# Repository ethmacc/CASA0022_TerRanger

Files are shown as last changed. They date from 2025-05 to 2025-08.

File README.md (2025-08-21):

# CASA0022 TerRanger

IMG_0298 (1)

## Contents
1. [Introduction](#Introduction)
3. [Materials](#Materials)
4. [Quickstart](#Quickstart)
5. [Advanced Setup](#Advanced-setup)
8. [Future Work](#future-work)
9. [External Links](#External-links)
10. [References](#References)
11. [Contact](#Contact)

## Introduction
### Demo Film
TerRanger Demo Film (https://www.youtube.com/watch?v=eogr--X4ssc)

### What is TerRanger?
This repository contains the code and 3D models required to build the TerRanger Smart Walking Stick, my dissertation project for the MSc Connected Environments course. The TerRanger system consists of 2 key components: the smart walking stick device and a mobile application that pairs with it using Bluetooth Low Energy (BLE). TerRanger uses two STMicroelectronics VL53L5CX tiny LiDAR sensors to map out the terrain below the hiking stick. This data is then translated into point-cloud form and visualized on the mobile application. TerRanger utilises the terrain surface data to estimate erosion along hiking paths, and is essentially a feasibility study to show that trail erosion monitoring can be semi-automated using embedded, low-cost technology.

## Materials
You will need the following materials:
- A 3D printer (with nozzle size no larger than 0.4mm) & filament
- A UV printer (optional)
- An Arduino Nano BLE 33 Sense (rev1 was used in this build, but rev2 can probably also be used with some modifications)
- Protoboard or stripboard
- Electrical wire
- A capacitor (at least 33µF)
- A 10kΩ resistor
- A tactile button
- A 5V stepup converter/regulator (Pololu 5V S7V8F5)
- A LiPo charging module (Adafruit bq24074)
- A 2000mAh LiPo cell
- 2 x VL53L5CX LiDAR Time-of-Flight sensors
- A toggle switch
- 2x 4 pin JST-SH cables
- Assorted M2 screws and bolts
- Washers
- Pin headers and sockets
- Velcro strap
- A walking stick for hiking
- An Android smartphone

## Quickstart
### Hardware
To construct the electronics, the protoboard/stripboard should first be cut to the dimensions 51mm x 62mm. Then, the circuit can be constructed using the following breadboard and schematic as a guide:

circuit_diagram_bb

*Fritzing breadboard diagram*

circuit_diagram_schem

*Fritzing circuit schematic*

The circuit contains a number of subcircuits for the following components:

| **Component subcircuit** | **Remarks** |
|---|---|
| LiDAR sensors | These should be attached using JST-SH cables can for ease of maintenance and disassembly. However, if you wish, they can also be connected with solder joints. Ensure that the four individal lines of the JST-SH connection are connected to the appropriate pins of the Nano 33 MCU (3.3V, ground, I2C - SDA & SCL). The green lines in the breadboard diagram denote the LPn connections, and these MUST be connected to the MCU at the appropriate pins to allow for the individual I2C addresses for each sensor to be assigned correctly. |
| Tactile button | This is connected using a [standard click button circuit](https://docs.arduino.cc/built-in-examples/digital/Button/) to receive a signal when the button is pressed. The 10kΩ resistor is used here. |
| 5V step-up | This part of the circuit boosts the 3.7V of the LiPo battery to 5V so that it can be fed into the Nano 33's VIN pin. The 33µF capacitor is used here to provide some smoothing when the toggle switch is turned on. |
| LiPo charger | This charges the LiPo battery whilst also providing 3.7V from the battery to the 5V step-up. Note that the orientation of the ports should be the same direction as the Nano 33's micro-usb port. This was done for ease of maintenance |

The following real images can also be used as a reference in the protoboard construction:
protoboard

*Protoboard initial build*

protoboard in enclosure

*Protoboard fully connected to components and placed in enclosure*

The device has an approximate endurance of about 8 hours, based on current draw of the circuit as measured below (0.25A).

Circuit current draw as measured with a multimeter

*Circuit current draw as measured with a multimeter*

### Software
The Arduino C++ code for the device is provided in the following folders:
- ```Arduino/DistanceArray_main``` - Push this version to the Nano 33 for the initial device that uses the manual tactile button to trigger the LiDAR sensors to take a sample
- ```Arduino/DistanceArray_ai``` - Push this version to the Nano 33 for the later device that uses gesture recognition (a double tap of the walking stick) to trigger the LiDAR sensors to take a sample

### Enclosure
The enclosure can be printed by exporting the various components from the Fusion360 file in ```Models/3D/```. Ensure the 3D models are printed with sufficiently high quality settings for the best results. The black charging port cover (in the image below) should be printed with flexible polymer, such as TPU. M2 screws and bolts should be used to secure the two halves of the enclosure together.

TPU charging port cover 1
TPU charging port cover 2

*TPU charging port cover*



*Fusion360 model of the device enclosure*

The Fusion360 model can also be used as a reference to attach the electronics inside the enclosure correctly. The 2000mAh LiPo battery should be placed behind the protoboard, and can be pushed into place with a felt ribbon to make removing it easier:




*Removing the battery from the device with a felt ribbon*

If you wish, and have access to a UV printer, you can apply the decals found in ```Models/2D``` to the front face of the enclosure.



*Developing the UV print design*

### Mobile Application
The Mobile Application was designed initially in Figma and then realised with Flutter.

Mobile Application Wireframe

*Wireframe for the TerRanger Mobile Application, designed in Figma*






*Screens from the finished Flutter build*

To download the latest version of the application, navigate to the [Releases tab](https://github.com/ethmacc/CASA0022_TerRanger/releases) and download the latest release.

### Device Operation
Once the device has been assembled and the mobile application installed on your Android smartphone, follow these steps to prepare the device for use:
1. Thread the velcro strap through the slots in the bracket at the back of the enclosure. Use these to securely attach the TerRanger device to your hiking stick
2. Switch on TerRanger by flipping the toggle switch at the top of the enclosure and wait for a few seconds for the startup routine to complete
3. Pair the device by navigating to the ```Devices``` screen in the mobile application and pressing the ```Connect to device``` button.
4. Once done, use the red-orange centre button in the middle of the bottom app bar to create a new hike and start collecting data

## Advanced Setup

This section is intended for advanced makers to provide further details on the TerRanger system and how these can be modified.

### Software

#### Dependencies

The following key libraries were used in the Arduino code:

| **Library** | **Purpose** |
|---|---|
| [vector](https://docs.arduino.cc/libraries/vector/) | Used for [Gyroscopic compensation](#Gyroscopic-compensation) |
| [Wire](https://docs.arduino.cc/language-reference/en/functions/communication/wire/) | Required for I2C communication between the LiDAR sensors and the MCU |
| [SparkFun_VL53L5CX_Library](https://docs.arduino.cc/libraries/sparkfun-vl53l5cx-arduino-library/) | Required to interface with the firmware for the VL53L5CX |
| [ArduinoBLE](https://docs.arduino.cc/libraries/arduinoble/) | Used to set a device name and create a BLE characteristic that the data from the sensors can be written to |
| [Arduino_LSM9DS1](https://docs.arduino.cc/libraries/arduino_lsm9ds1/) | To interface with the LSM9DS1 IMU, used for [Gyroscopic compensation](#Gyroscopic-compensation) |

#### Sensor tuning

Image of two VL53L5CX sensors attached to the circuit

*Two VL53L5CX sensors attached to the circuit*

The VL53L5CX sensors can be tuned to change their sampling frequency, distance array size and ranging mode, which will have effects on device performance. This can be done by calling the appropriate functions from the imported Sparkfun library in the main Arduino code, for example:

| **Function** | **Use** |
|---|---|
| `SparkFun_VL53L5CX.setResolution()` | To change distance array size between 4x4 and 8x8 |
| `SparkFun_VL53L5CX.setRangingMode()` | To set ranging mode. It is possible to select either continuous or autonomous. Continuous uses more power but is more frequent |
| `SparkFun_VL53L5CX..setRangingFrequency()` | To set ranging frequency in continous mode. This has been set to the maximum of 60Hz in the code, to minimize lag time |

For more information, see the Sparkfun VL53L5CX library GitHub repo and VL53L5CX datasheet and manual under [External Links](#External-links))

#### Gyroscopic compensation

The walking stick could be oriented in a direction that is not orthogonal to the ground plane when a sample is taken. Therefore the vector library was used, and the functions ```calculatePitch``` and ```calculateYaw``` make use of this and the [acceleration to pitch & yaw forumla](https://wiki.dfrobot.com/How_to_Use_a_Three-Axis_Accelerometer_for_Tilt_Sensing) to convert the accelerometer readings to pitch and yaw angles in degrees. These angles are transmitted to the mobile application via Bluetooth.

#### Bluetooth

The device connects to the mobile application via Bluetooth Low Energy, using the Arduino BLE library. The buffer size (for transmitting data) has been set up dynamically using variables to ensure it will change should you choose to set the VL53L5CX to the 8x8 resolution (it is set to 4x4 by default and in the code). Note that this may also require changes to the peripheral BLE device code in the mobile application as it is currently configured to receive the appropriate number of btyes for the 4x4 resolution, not the 8x8.

### Edge AI model

If you elect to use the gesture recognition version of the Arduino code in ```Arduino/DistanceArray_ai/```, you will find that it uses a TinyML or Edge AI model to power the gesture recognition functionality. The model embedded in the code as a library is a Convolutional Neural Network (CNN), that has been trained on accelerometer data from performing the gesture of double tapping the hiking stick on the ground.



*Model architecture of the CNN used for gesture recognition in the DistanceArray_ai.ino file*

Other architectures tested included a Recurrent Neural Network (using Long Short Term Memory layers) and a hybrid model with both LSTM and Convolutional layers. The CNN model outperformed the other two architectures by far.



*Comparison of performance across different model architectures*

Using Edge Impulse, it is possible to clone the project and train it on your own data or make further adjustments to the model. To visit the Edge Impulse project page, see [External Links](#External-links))

### Mobile Application

#### Dependencies

The key libraries that have been used in the code are:

| **Library** | **Purpose** |
|---|---|
| [flutter_reactive_ble](https://pub.dev/packages/flutter_reactive_ble) | For establishing the Bluetooth Low Energy connection to the device |
| [permission_handler](https://pub.dev/packages/permission_handler) | For handling location and Bluetooth permissions |
| [provider](https://pub.dev/packages/provider) | To provide [app state management](https://docs.flutter.dev/get-started/fundamentals/state-management) |
| [sqflite](https://pub.dev/packages/sqflite) | To persist data in the background in the form of a SQL database |
| [flutter_map](https://pub.dev/packages/flutter_map) & [flutter_map_location_marker](https://pub.dev/packages/flutter_map_location_marker) | To display a map widget |
| [latlong2](https://pub.dev/packages/latlong2) & [geolocator](https://pub.dev/packages/geolocator) | To get the position of the user when a sample is taken |
| [fl_chart](https://pub.dev/packages/fl_chart), [vector_math](https://pub.dev/packages/vector_math) & [ditredi](https://pub.dev/packages/ditredi) | To manipulate and visualize the data from the sensors |
| [share_plus](https://pub.dev/packages/share_plus) | To provide backup functionality for the local SQL database where the data is stored |

#### Developer setup

If you wish to develop the mobile application further, first clone this entire repository with:

```powershell
git clone https://github.com/ethmacc/CASA0022_TerRanger/
```

After which, run the following command to fix and issues in the code and install dependencies (using the ```pubspec.yaml``` file in application root folder):

```powershell
flutter clean

flutter pub get
```

To run the application in a connected Android Device or Emulator, use:

```powershell
flutter run
```

The application can be built into and apk and installed using the following commands:

```powershell
flutter build apk
flutter install
```

Note that if you want to push an upgrade to an existing version of the application on your Android device without overwriting the existing data collected, you should use:

```powershell
adb install -r "smarthiking_app\build\app\outputs\apk\release\app-release.apk"
```

instead of ```flutter install```

If you wish to load data from the 3 hikes that were conducted during the course of this project, find them in the folder ```Data/database_backups/``` and load them into your app by using the load backup function on the backups screen.

#### Algorithms
The distance array (from the VL53L5CX sensors) to point-cloud algorithm is based on scaling a list of vectors that point to each of the grid points in the sensor's field of view. This was tested and visualised initially in the Python notebooks  ```/Data/byte_decoder.ipynb``` and ```/Data/byte_decoder_4x4.ipynb```, which can also be used for further development.

newplot (1)

*The vector list visualised as a vector field using plotly in the Python notebook*

The vector list has been copied and hardcoded into ```smarthiking_app/lib/screens/sample_detail.dart``` and is used in the function
```dart
List<List> parseAndScalePts(String rawData) {...}
```
to generate the point cloud from the distance array received from the sensors.

The erosion estimation algorthim is based on the Cross-Section Analysis (CSA) method and formula as described in [Olive and Marion (2009)](#references):



*Diagram illustraing the CSA method, taken from [Olive and Marion (2009)](#references)*

This is implemented in ```smarthiking_app/lib/screens/sample_detail.dart``` in the function:
```dart
double calcErosion (List<List> sectionLists) {...}
```

## Future Work
A PCB design was developed towards the end of the project, but this was not manufactured or tested. It can be found in ```Models/2D```. A future version of the project might involve miniaturising the device further, taking and advantage of the reduced size of the electronics with a dedicated PCB and surface mount-components.




*PCB design schematic (left) and 3D model (right)*

It may also be possible to upgrade the sensors, which during testing were found to be less accurate than desired. The VL53L8CX, an improved model that is more able to cope with environmental factors such as high ambient light, is just starting to become more widely available.

Lastly, it would be an interesting exercise to try adapting the device to another use case, such as surveying for potholes. Pothole damage repair costs the UK approximately £143.5 million annually [(Asphalt Industry Alliance, 2024)](#references).

## External Links

### Sparkfun VL53L5CX library
https://github.com/sparkfun/SparkFun_VL53L5CX_Arduino_Library

### VL53L5CX manual & datasheet
https://www.st.com/resource/en/user_manual/um2884-a-guide-to-using-the-vl53l5cx-multizone-timeofflight-ranging-sensor-with-a-wide-field-of-view-ultra-lite-driver-uld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

https://www.st.com/resource/en/datasheet/vl53l5cx.pdf

### Edge Impulse Project
https://studio.edgeimpulse.com/public/732758/live

## References

### In text

Asphalt Industry Alliance. (2024). *Annual Local Authority Road Maintenance Survey Report*. 2024.

Olive, N. D. and Marion, J. L. (2009). *‘The influence of use-related, environmental, and managerial factors on soil loss from recreational trails’. Journal of Environmental Management*, 90 (3), pp. 1483–1493. doi: 10.1016/j.jenvman.2008.10.004.

### Code snippets & tutorials

Makadiya, K (2024). *Flutter Pull to Refresh: How to Implement, Customize, and Handle Errors. Dhiwise.com*. Available at: https://www.dhiwise.com/post/flutter-pull-to-refresh-how-to-implement-customize (Accessed 20 Aug. 2025).

Lee, S. (2024). *Safely Backing Up Sqlflite in Flutter. Medium*. Available at: https://medium.com/@soojlee0701/safely-backing-up-sqlflite-in-flutter-120718588dd5 (Accessed 20 Aug. 2025).

Nitesh (2021). *Flutter polyline distance with google_maps_flutter plugin. Stack Overflow*. Available at: https://stackoverflow.com/questions/66181115/flutter-polyline-distance-with-google-maps-flutter-plugin (Accessed 21 Aug. 2025).

VitLit (2019). *Center poly line google maps plugin flutter fit to screen google map. Stack Overflow*. Available at: https://stackoverflow.com/questions/57986855/center-poly-line-google-maps-plugin-flutter-fit-to-screen-google-map (Accessed 21 Aug. 2025).

## Contact
If you have any suggestions or would like to contribute to this project, please submit a pull request and/or contact me using my social links on my profile

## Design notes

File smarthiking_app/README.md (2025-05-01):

# smarthiking_app

A new Flutter project.

## Getting Started

This project is a starting point for a Flutter application.

A few resources to get you started if this is your first Flutter project:

- [Lab: Write your first Flutter app](https://docs.flutter.dev/get-started/codelab)
- [Cookbook: Useful Flutter samples](https://docs.flutter.dev/cookbook)

For help getting started with Flutter development, view the
[online documentation](https://docs.flutter.dev/), which offers tutorials,
samples, guidance on mobile development, and a full API reference.

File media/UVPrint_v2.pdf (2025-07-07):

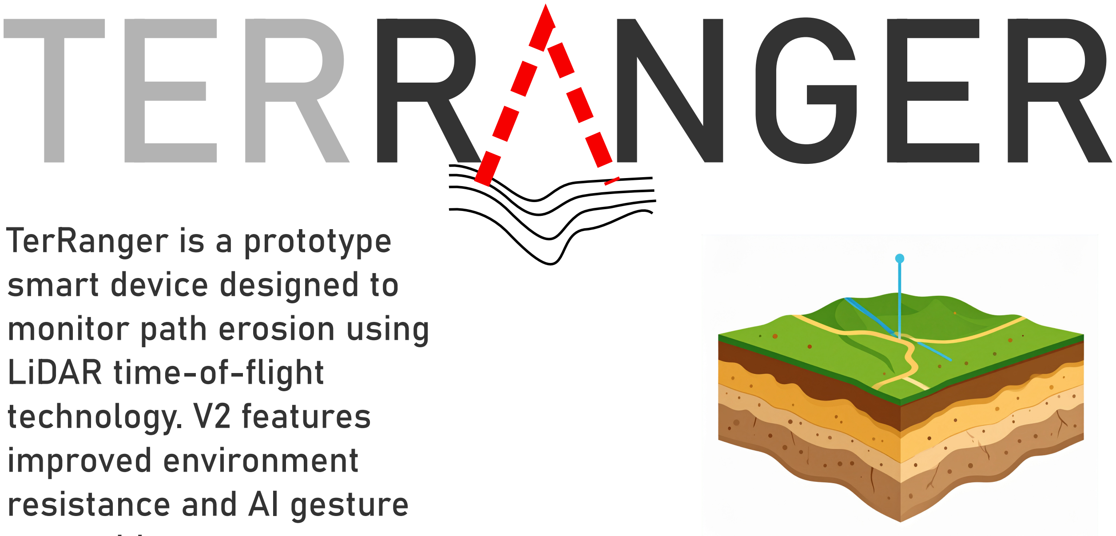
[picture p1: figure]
TERR NGER; TerRanger is a prototype smart device designed to monitor path erosion using LiDAR time-of-flight technology. V2 features improved environment resistance and AI gesture
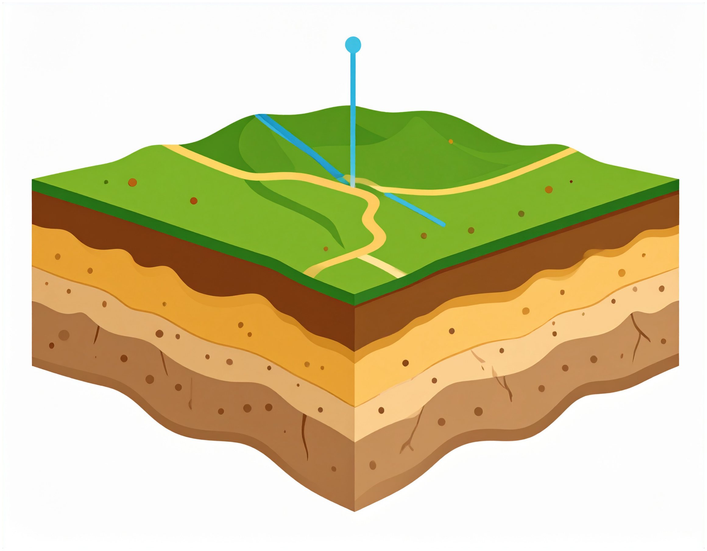
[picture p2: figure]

recognition.

TerRanger v2.0.2025

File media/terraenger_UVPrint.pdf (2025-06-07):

# TERRAENGER

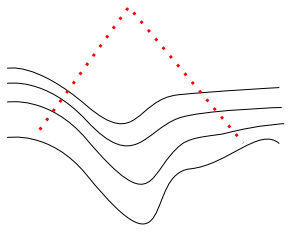
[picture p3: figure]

Terraenger is a prototype
smart device designed to
monitor path erosion using LiDAR time-of-flight
technology

Terraenger v1.0.2025

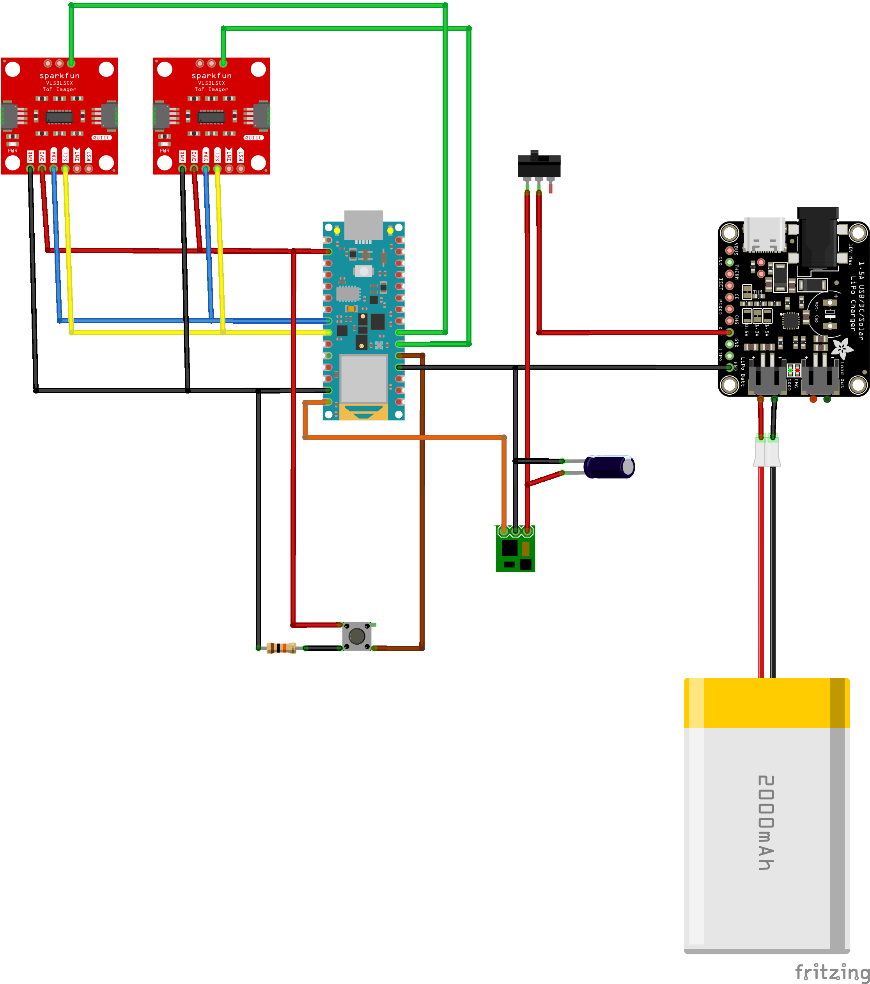
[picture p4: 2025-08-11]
Models/2D/circuit_diagram_bb.png

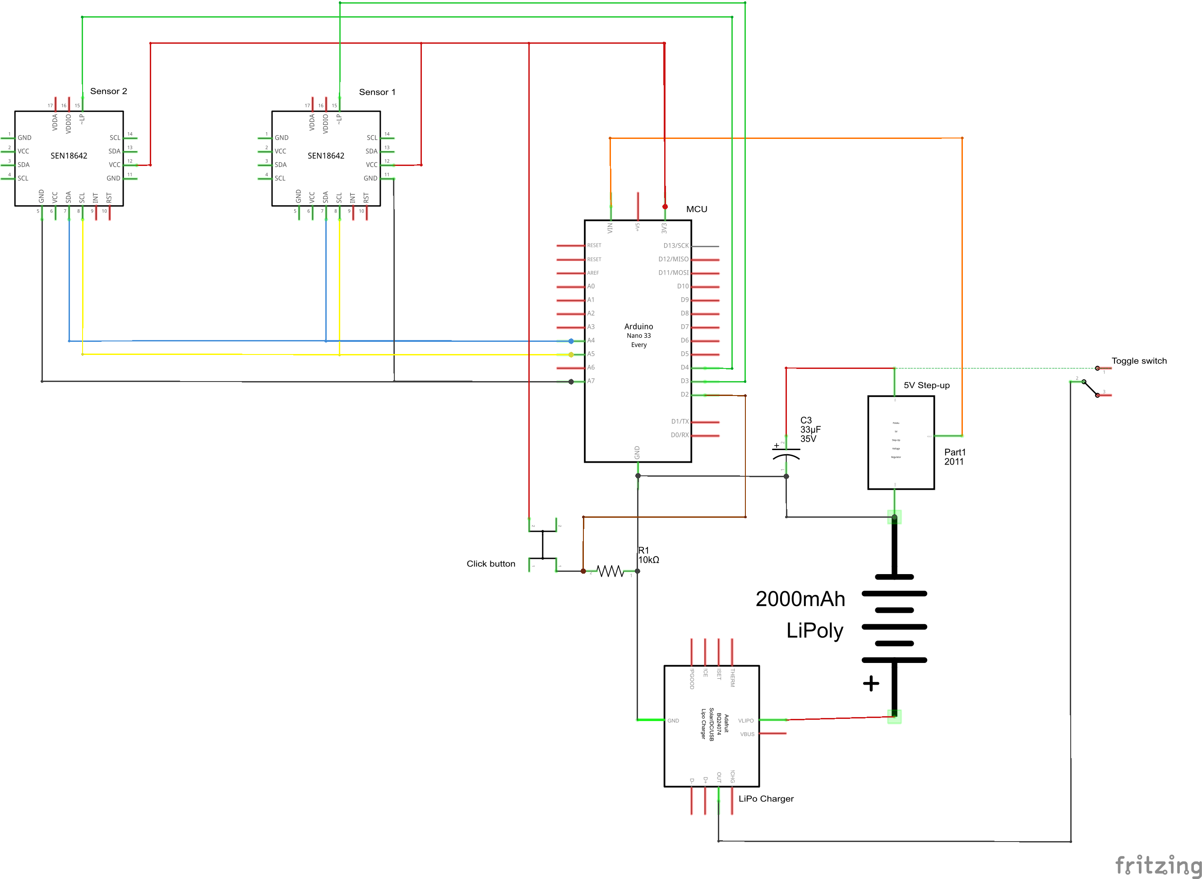
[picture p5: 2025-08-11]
Models/2D/circuit_diagram_schem.png

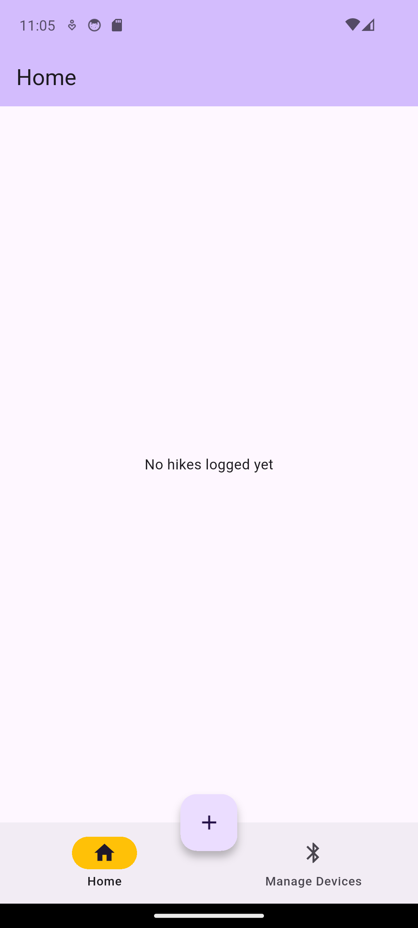
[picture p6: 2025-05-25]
smarthiking_app/flutter_01.png

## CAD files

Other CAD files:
Models/3D/TerRanger_main.f3d

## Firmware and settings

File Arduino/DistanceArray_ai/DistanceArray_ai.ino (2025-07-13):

#include <vector>
#include <Wire.h> //include Wire for I2C
#include <SparkFun_VL53L5CX_Library.h> //http://librarymanager/All#SparkFun_VL53L5CX
#include <ArduinoBLE.h>
#include <Arduino_LSM9DS1.h>
#include <TerRanger_inferencing.h>

SparkFun_VL53L5CX tof_1;
SparkFun_VL53L5CX tof_2;
VL53L5CX_ResultsData measurementData_1; // Result data class structure, 1356 byes of RAM
VL53L5CX_ResultsData measurementData_2;

uint8_t percent = 30; // Set sharpening percentage
uint8_t freq = 30; // Set ranging frequency
uint8_t res = 4*4; // Set sensor resolution

int imageResolution = 0; //Used to pretty print output
int imageWidth = 0; //Used to pretty print output

#define LPn_1 D3
#define LPn_2 D4

#define buttonPin D2 //Set pin for the button
int buttonState = 0;

// Bluetooth® Low Energy Service
#define BUFFER_SIZE ( (res * 2 ) + 2) * 2 // Buffer size is resolution x 2 sensors x 2 bytes plus 2 * 2 bytes for acc data
BLEService tofService = BLEService("185B");
BLECharacteristic tofChar = BLECharacteristic("2C0A", BLERead | BLENotify, BUFFER_SIZE, false); 

#define CONVERT_G_TO_MS2    9.80665f
#define MAX_ACCEPTED_RANGE  2.0f

static bool debug_nn = false; // Set this to true to see e.g. features generated from the raw signal
static uint32_t run_inference_every_ms = 30;
static rtos::Thread inference_thread(osPriorityLow);

static float buffer[EI_CLASSIFIER_DSP_INPUT_FRAME_SIZE] = { 0 };
static float inference_buffer[EI_CLASSIFIER_DSP_INPUT_FRAME_SIZE];

const char *prediction = "false";

/* Forward declaration */
void run_inference_background();

float accX, accY, accZ;

unsigned long pressTime = millis();

void setup()
{
  Serial.begin(115200);
  delay(1000);  

  // Set LED for BLE connection indicator
  pinMode(LED_BUILTIN, OUTPUT);

  //Initialise I2C
  Wire.begin(); //This resets to 100kHz I2C
  Wire.setClock(400000); //Sensor has max I2C freq of 400kHz 
  
  //Initialise ToF
  Serial.println("Initializing ToF sensors. This can take up to 10s. Please wait.");

  //Initialise ToF cams
  initialiseToF(1);
  initialiseToF(2);

  imageResolution = tof_1.getResolution(); //Query sensor for current resolution - either 4x4 or 8x8
  imageWidth = sqrt(imageResolution); //Calculate printing width

  //IMU initialisation
  if (!IMU.begin()) {
    Serial.println("Failed to initialize IMU!");
    while (1);
  }
  Serial.println("IMU initialised");

  // BLE begin initialization
  if (!BLE.begin()) {
    Serial.println("starting BLE failed!");
    while (1);
  }
  Serial.println("BLE initialised");

  //BLE set device name, UUIDs 
  BLE.setLocalName("SH_v1");
  BLE.setDeviceName("SH_v1");

  BLE.setAdvertisedService(tofService);
  tofService.addCharacteristic(tofChar);
  BLE.addService(tofService);
  BLE.advertise();

  //Edge Impulse model axes check
  if (EI_CLASSIFIER_RAW_SAMPLES_PER_FRAME != 6) {
        ei_printf("ERR: EI_CLASSIFIER_RAW_SAMPLES_PER_FRAME should be equal to 6 (the 6 sensor axes)\n");
        return;
  }

  inference_thread.start(mbed::callback(&run_inference_background));
  Serial.println("Inference thread started");

  Serial.println("All initialisation complete");
}

void loop()
{
  // wait for a Bluetooth® Low Energy central
  BLEDevice central = BLE.central();

  // if a central is connected to the peripheral:
  if (central) {
    Serial.print("Connected to central: ");
    // print the central's BT address:
    Serial.println(central.address());
    // turn on the LED to indicate the connection:
    digitalWrite(LED_BUILTIN, HIGH);

    while (central.connected()) {
      ///Poll sensors and load buffer//
      // Determine the next tick (and then sleep later)
      uint64_t next_tick = micros() + (EI_CLASSIFIER_INTERVAL_MS * 1000);

      // roll the buffer -3 points so we can overwrite the last one
      numpy::roll(buffer, EI_CLASSIFIER_DSP_INPUT_FRAME_SIZE, -6);

      // read to the end of the buffer
      IMU.readAcceleration(
          buffer[EI_CLASSIFIER_DSP_INPUT_FRAME_SIZE - 6],
          buffer[EI_CLASSIFIER_DSP_INPUT_FRAME_SIZE - 5],
          buffer[EI_CLASSIFIER_DSP_INPUT_FRAME_SIZE - 4]
      );

      IMU.readGyroscope(
          buffer[EI_CLASSIFIER_DSP_INPUT_FRAME_SIZE - 3],
          buffer[EI_CLASSIFIER_DSP_INPUT_FRAME_SIZE - 2],
          buffer[EI_CLASSIFIER_DSP_INPUT_FRAME_SIZE - 1]
      );

      for (int i = 0; i < 6; i++) {
          if (fabs(buffer[EI_CLASSIFIER_DSP_INPUT_FRAME_SIZE - 6 + i]) > MAX_ACCEPTED_RANGE) {
              buffer[EI_CLASSIFIER_DSP_INPUT_FRAME_SIZE - 6 + i] = ei_get_sign(buffer[EI_CLASSIFIER_DSP_INPUT_FRAME_SIZE - 6 + i]) * MAX_ACCEPTED_RANGE;
          }
      }

      buffer[EI_CLASSIFIER_DSP_INPUT_FRAME_SIZE - 6] *= CONVERT_G_TO_MS2;
      buffer[EI_CLASSIFIER_DSP_INPUT_FRAME_SIZE - 5] *= CONVERT_G_TO_MS2;
      buffer[EI_CLASSIFIER_DSP_INPUT_FRAME_SIZE - 4] *= CONVERT_G_TO_MS2;

      // check if the pushbutton is pressed. If it is, the buttonState is HIGH:
      
      if (prediction == "true" && millis() - pressTime > 1000) {
        Serial.println("prediction true");
        
        Serial.println("ToF cam1");
        updateDistance(1);
        Serial.println("ToF cam2");
        updateDistance(2);

        if (IMU.accelerationAvailable()) {
          IMU.readAcceleration(accX, accY, accZ);
        }

        float consX = constrain(accX, -1.0, 1.0);
        float consY = constrain(accY, -1.0, 1.0);
        float consZ = constrain(accZ, -1.0, 1.0);

        int roll = calculateRoll(consX, consY, consZ);
        int pitch  = calculatePitch(consX, consY, consZ);

        Serial.println(roll);
        Serial.println(pitch);

        uint16_t roll16 = uint16_t(roll + 180);
        uint16_t pitch16 = uint16_t(pitch + 180);

        Serial.println(roll16);
        Serial.println(pitch16);
          
        uint16_t acc_data[2] = {roll16, pitch16};

        uint16_t * combined_tof = new uint16_t[res * 2];
        std::copy(measurementData_1.distance_mm, measurementData_1.distance_mm + res, combined_tof);
        std::copy(measurementData_2.distance_mm, measurementData_2.distance_mm + res, combined_tof + res);

        uint16_t * all_data = new uint16_t[(res * 2) + 2];
        std::copy(combined_tof, combined_tof + (res * 2), all_data);
        std::copy(acc_data, acc_data + 2, all_data + (res * 2));
        
        tofChar.writeValue(all_data, BUFFER_SIZE);
        pressTime = millis();
      }

      // and wait for next tick
      uint64_t time_to_wait;
      if (micros() >= next_tick) {
          time_to_wait = 0;
      } else {
          time_to_wait = next_tick - micros();
      }
      
      delay((int)floor((float)time_to_wait / 1000.0f));
      delayMicroseconds(time_to_wait % 1000);
    }
     // when the central disconnects, turn off the LED:
    digitalWrite(LED_BUILTIN, LOW);
    Serial.print("Disconnected from central: ");
    Serial.println(central.address());
  }
}
 
void updateDistance(int cam) {
  switch (cam) {
    case 1:
      //Poll sensor for new data
      if (tof_1.isDataReady() == true)
      {
        if (tof_1.getRangingData(&measurementData_1)) //Read distance data into array
        {
          //tofChar.writeValue(measurementData_1.distance_mm, 128);
          //The ST library returns the data transposed from zone mapping shown in datasheet
          //Pretty-print data with increasing y, decreasing x to reflect reality
          for (int y = 0 ; y <= imageWidth * (imageWidth - 1) ; y += imageWidth)
          {
            for (int x = imageWidth - 1 ; x >= 0 ; x--)
            {
              Serial.print("\t");
              Serial.print(measurementData_1.distance_mm[x + y]);
            }
            Serial.println();
          }
          Serial.println();
        }
      }
      break;
    case 2:
      //Poll sensor for new data
      if (tof_2.isDataReady() == true)
      {
        if (tof_2.getRangingData(&measurementData_2)) //Read distance data into array
        {
          //tofChar.writeValue(measurementData_1.distance_mm, 128);
          //The ST library returns the data transposed from zone mapping shown in datasheet
          //Pretty-print data with increasing y, decreasing x to reflect reality
          for (int y = 0 ; y <= imageWidth * (imageWidth - 1) ; y += imageWidth)
          {
            for (int x = imageWidth - 1 ; x >= 0 ; x--)
            {
              Serial.print("\t");
              Serial.print(measurementData_2.distance_mm[x + y]);
            }
            Serial.println();
          }
          Serial.println();
        }
      }
      break;
  }
  
}

void initialiseToF (int cam) {
  switch (cam) {
    case 1:
      digitalWrite(LPn_1, HIGH);
      digitalWrite(LPn_2, LOW);

      if (tof_1.begin() == false)
      {
        Serial.println(F("Sensor 1 not found - check your wiring. Freezing"));
        while (1);
      }
      tof_1.setAddress(0x50);
      tof_1.setResolution(res); 
      tof_1.setSharpenerPercent(percent); //increase sharpener slightly to reduce veiling glare
      tof_1.setRangingMode(SF_VL53L5CX_RANGING_MODE::CONTINUOUS);
      tof_1.setRangingFrequency(freq); // increase ranging frequency to 15Hz to reduce lag
      tof_1.startRanging();
      break;
    case 2:
      digitalWrite(LPn_1, LOW);
      digitalWrite(LPn_2, HIGH);

      if (tof_2.begin() == false)
      {
        Serial.println(F("Sensor 2 not found - check your wiring. Freezing"));
        while (1);
      }
      tof_2.setAddress(0x51);
      tof_2.setResolution(res); 
      tof_2.setSharpenerPercent(percent);
      tof_2.setRangingMode(SF_VL53L5CX_RANGING_MODE::CONTINUOUS);
      tof_2.setRangingFrequency(freq); // increase ranging frequency to 15Hz to reduce lag
      tof_2.startRanging();
      break;
  }
  Serial.print(F("Sensor "));
  Serial.print(cam);
  Serial.println(F(" ready"));

  //Ensure all sensors awake
  digitalWrite(LPn_1, HIGH);
  digitalWrite(LPn_2, HIGH);
}

int calculateRoll(float x, float y, float z) {
  return atan2(y , z) * 57.3;
}

int calculatePitch(float x, float y, float z) {
  return atan2((- x) , sqrt(y * y + z * z)) * 57.3;
}

float ei_get_sign(float number) {
    return (number >= 0.0) ? 1.0 : -1.0;
}

void run_inference_background()
{
    // wait until we have a full buffer
    delay((EI_CLASSIFIER_INTERVAL_MS * EI_CLASSIFIER_RAW_SAMPLE_COUNT) + 100);

    // This is a structure that smoothens the output result
    // With the default settings 70% of readings should be the same before classifying.
    ei_classifier_smooth_t smooth;
    ei_classifier_smooth_init(&smooth, 10 /* no. of readings */, 7 /* min. readings the same */, 0.8 /* min. confidence */, 0.3 /* max anomaly */);

    while (1) {
        // copy the buffer
        memcpy(inference_buffer, buffer, EI_CLASSIFIER_DSP_INPUT_FRAME_SIZE * sizeof(float));

        // Turn the raw buffer in a signal which we can the classify
        signal_t signal;
        int err = numpy::signal_from_buffer(inference_buffer, EI_CLASSIFIER_DSP_INPUT_FRAME_SIZE, &signal);
        if (err != 0) {
            ei_printf("Failed to create signal from buffer (%d)\n", err);
            return;
        }

        // Run the classifier
        ei_impulse_result_t result = { 0 };

        err = run_classifier(&signal, &result, debug_nn);
        if (err != EI_IMPULSE_OK) {
            ei_printf("ERR: Failed to run classifier (%d)\n", err);
            return;
        }

        // print the predictions
        ei_printf("Predictions ");
        ei_printf("(DSP: %d ms., Classification: %d ms., Anomaly: %d ms.)",
            result.timing.dsp, result.timing.classification, result.timing.anomaly);
        ei_printf(": ");

        // ei_classifier_smooth_update yields the predicted label
        prediction = ei_classifier_smooth_update(&smooth, &result);
        ei_printf("%s ", prediction);
        // print the cumulative results
        ei_printf(" [ ");
        for (size_t ix = 0; ix < smooth.count_size; ix++) {
            ei_printf("%u", smooth.count[ix]);
            if (ix != smooth.count_size + 1) {
                ei_printf(", ");
            }
            else {
              ei_printf(" ");
            }
        }
        ei_printf("]\n");

        delay(run_inference_every_ms);
    }

    ei_classifier_smooth_free(&smooth);
}

#if !defined(EI_CLASSIFIER_SENSOR) || EI_CLASSIFIER_SENSOR != EI_CLASSIFIER_SENSOR_FUSION
#error "Invalid model for current sensor"
#endif

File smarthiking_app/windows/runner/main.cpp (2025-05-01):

#include <flutter/dart_project.h>
#include <flutter/flutter_view_controller.h>
#include <windows.h>

#include "flutter_window.h"
#include "utils.h"

int APIENTRY wWinMain(_In_ HINSTANCE instance, _In_opt_ HINSTANCE prev,
                      _In_ wchar_t *command_line, _In_ int show_command) {
  // Attach to console when present (e.g., 'flutter run') or create a
  // new console when running with a debugger.
  if (!::AttachConsole(ATTACH_PARENT_PROCESS) && ::IsDebuggerPresent()) {
    CreateAndAttachConsole();
  }

  // Initialize COM, so that it is available for use in the library and/or
  // plugins.
  ::CoInitializeEx(nullptr, COINIT_APARTMENTTHREADED);

  flutter::DartProject project(L"data");

  std::vector<std::string> command_line_arguments =
      GetCommandLineArguments();

  project.set_dart_entrypoint_arguments(std::move(command_line_arguments));

  FlutterWindow window(project);
  Win32Window::Point origin(10, 10);
  Win32Window::Size size(1280, 720);
  if (!window.Create(L"smarthiking_app", origin, size)) {
    return EXIT_FAILURE;
  }
  window.SetQuitOnClose(true);

  ::MSG msg;
  while (::GetMessage(&msg, nullptr, 0, 0)) {
    ::TranslateMessage(&msg);
    ::DispatchMessage(&msg);
  }

  ::CoUninitialize();
  return EXIT_SUCCESS;
}

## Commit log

2025-05-01 Add test arduino scripts plus flutter app template
2025-05-05 feat: Add support for 2x ToF on I2C bus
2025-05-14 Add permission handler, app connects successfully to arduino
2025-05-19 Feat: add full bottom navbar functionality and device connected green badge
2025-05-19 Add floating action button
2025-05-25 Add models, linkup database backend to frontend, add listview and cards to UI
    [bracket1.stl, bracket2.stl, button.stl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]
2025-05-26 feat: add polyline plotting at sample location
2025-05-28 Add sample detail page
2025-05-29 feat: successfully added lidar scatter chart
2025-05-30 Build up sample_detail page and add functionality to display separate 2D sections
    [SmartWalkingStick_enclosure v22.stl, bracket1_rev1.f3d, bracket1_rev1.stl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]
2025-06-02 fix: resolve geolocator slow response time on real device
2025-06-03 Add IMU compensation
2025-07-07 Make a start on picture capture function
    [smark_hiking_v2.3mf, v2_battery_restrictor.stl, v2_bracket1.stl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]
2025-08-04 Add improved point colouring function
    [circuit_diagram.fzz, exhibition_bracket.3mf, exhibition_bracket.stl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]
2025-08-11 Clean up
    [SmartWalkingStick_enclosure v22.stl, bracket1.stl, bracket1_rev1.f3d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]
2025-08-20 Add Fusion360 original file
    [TerRanger_main.f3d]
